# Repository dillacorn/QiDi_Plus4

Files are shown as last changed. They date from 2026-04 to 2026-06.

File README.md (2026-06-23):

# QiDi_Plus4

My Orca Slicer settings for the QiDi Plus4, with QiDi Box support and maintained Klipper `gcode_macro.cfg` / `printer.cfg` adjustments that can be changed in the Fluidd UI.

## Important warnings

### Filament temperature swaps

* Be careful when switching from high temperature filaments to lower temperature filaments.
* The cutter can leave high temp filament in the hotend.
* Feeding lower temp filament after that can cause a jam.
* For mixed temperature swaps, manual unload and manual load is the safest method.
* If you manually extract high temp filament that is linked to the QiDi Box, also unload it from the QiDi Box afterward.

### Manual spool / NO AMS printing

* For manual spool printing while the QiDi Box is connected, use the `NO AMS` Orca printer profile.
* The `NO AMS` profile uses `AMS=0`, skips QiDi Box startup logic, and does not call `T0`.
* Without the `NO AMS` profile, start the print from the printer screen and disable QiDi Box there.
* A separate manual spool profile is optional, but it helps prevent mistakes.

### QiDi Box / AMS notes

* If a spool is unraveling in the QiDi Box AMS, check your rollers.
* QiDi Box essentially ruined one of my spools because a roller was not rolling smoothly.
* I resolved it by swapping rollers around. They pull out easily.

### Stock touchscreen / QIDI screen stack

I no longer use the stock QiDi Plus4 touchscreen.

On my setup, the stock screen / Makerbase stack kept running background processes such as `xindi` / `QIDILink-client` even when I was mainly using Fluidd. While troubleshooting repeated `MCU: Timer Too Close` and main-MCU communication shutdowns, `xindi` was one of the heavier CPU users on the printer host.

I now leave the stock screen disconnected and use Fluidd from a separate laptop / touchscreen device instead. This keeps the printer host focused on Klipper, Moonraker, Fluidd, and webcam streaming instead of also running the stock screen UI.

This is optional. If you rely on the stock screen, do not disable it.

Use the optional tuning script to disable, verify, or re-enable the stock screen / Makerbase stack:

[plus4-optional-tuning.sh](https://github.com/dillacorn/QiDi_Plus4/blob/main/plus4-optional-tuning.sh)

In the script menu:

* `Apply optimizations` → `Disable QIDI screen service / xindi completely`
* `Undo optimizations` → `Re-enable QIDI screen service / xindi`
* `View status` → check whether the QIDI screen / QIDILink processes are running

### External KlipperScreen client

If you want a compact touchscreen-style control UI without running KlipperScreen on the Plus4 host board, run KlipperScreen from a separate laptop or touchscreen device instead.

Guide:

[External KlipperScreen Client](docs/external-klipperscreen-client/README.md)

This keeps the KlipperScreen UI load off the printer host while still allowing control through Moonraker.

## Z-offset note

<sub>Source / credit: [Kuo Steps for Improving Z-Offset Reliability](https://github.com/qidi-community/Plus4-Wiki/blob/main/content%2FKuo-Steps-for-Improving-Z-Offset-Reliability%2FREADME.md)</sub>

In `gcode_macro.cfg` in the Fluidd UI, the default `get_zoffset` value is:

```jinja
{% set p = (-0.15 + printer.gcode_move.homing_origin.z)|float %}
```

My current value is:

```jinja
{% set p = (-0.07 + printer.gcode_move.homing_origin.z)|float %}
```

Do not treat `-0.15` as the correct value for every machine.

Use it as a starting point only. You will likely need to adjust this yourself based on your machine, filament, bed surface, and print temperatures until first-layer squish is correct.

## Bed leveling and tramming

I no longer use the stock printer screen, so I do bed leveling from the Fluidd console using the QiDi macros.

Do **not** use the generic Fluidd bed-mesh button if it only sends:

```gcode
BED_MESH_CALIBRATE
```

Use the QiDi bed-level macros instead:

```gcode
QIDI_BED_LEVEL_60
```

for PLA / low-temp bed leveling, or:

```gcode
QIDI_BED_LEVEL_100
```

for ASA / ABS bed leveling.

These macros follow the QiDi leveling path and are safer than running a bare `BED_MESH_CALIBRATE` from Fluidd.

If your bed mesh shows around `0.30` or higher out of level, re-tram the bed and recalibrate using `Z_TILT_ADJUST` plus the QiDi bed reset / bed-level macro path.

For the closest tram possible, I recommend this bed tramming tool:

[QiDi Plus 4 Bed Tramming Tool](https://www.printables.com/model/1364372-qidi-plus-4-bed-tramming-tool)

Use paper to manually find an even level. The paper should have some resistance under the nozzle, but it should still move without binding hard.

I recommend running the QiDi bed reset procedure at least twice.

While doing this, apply light pressure to the center of the bed so it sits completely flat. I have noticed the bed can have a little bit of give, and using a consistent pressure point helps get a closer tram. Release pressure and re-check the paper at the center and all four corners during the procedure.

## Recommended Plus4 upgrades

I recommend printing these mods in ASA.

### CNC-Machined Aluminum Extruder Tension Bar

After roughly six months of heavy use, my stock plastic extruder tension bar developed significant warping and flex. I highly recommend replacing it with the CNC-machined aluminum version for better long-term rigidity and consistent extruder tension.

- [QIDI 3D Printer Aluminum Extruder Tension Bar Upgrade](https://www.etsy.com/listing/4514278258/qidi-3d-printer-aluminum-extruder)
- [Photos, installation, and comparison](docs/Alu_Tension_Bar/README.md)

### HEPA filter and activated charcoal setup

* [Flush-fit HEPA filter with refillable charcoal tray](https://www.printables.com/model/1148756-qidi-plus-4-hepa-filter-flush-fit-with-refillable)
* [Activated carbon](https://www.amazon.com/Carbon-Filtration-Activated-Depot-Replacement/dp/B0DJTSD8K8)
* [HEPA filter material](https://www.amazon.com/dp/B075L64BM7)

### Exhaust and VOC / fume setup

* [Exhaust setup](https://www.thingiverse.com/thing:6794215)
* [4-inch duct line](https://www.amazon.com/iPower-Flexible-Inch-Feet-Aluminum/dp/B09B1TK2WL)
* [Adjustable 120mm fan](https://www.amazon.com/Easy-Cloud-Plug-120mm-Controller-Brushless/dp/B0BG4C9H5P)
* [120mm to 4-inch duct adapter](https://www.printables.com/model/820287-adapter-for-120mm-fan-to-4-inch-duct)
  Print two.
* [4-inch window duct mount](https://www.amazon.com/HOXHA-Window-Ducting-Portable-Inline/dp/B0FF4JRX53?s=appliances)

### QiDi Box mods

* [Bowden tube support / bracket for QiDi Box](https://www.printables.com/model/1408927-bowden-tube-support-qidi-plus-4-bracket-for-qidi-b)
* [Jam-resistant filament guide](https://www.printables.com/model/1386069-qidi-box-jam-resistant-filament-guide/files)
* [Bowden Y-splitter for QiDi Box AMS PC4-M6](https://www.printables.com/model/1413138-bowden-y-splitter-for-qidi-box-ams-pc4-m6)
* [Extended angled spool holder for use with QiDi Box](https://www.printables.com/model/1477082-qidi-plus-4-extended-angled-spool-holder-use-with)
* [Second spool holder and QiDi Box bracket](https://www.printables.com/model/1396483-qidi-plus-4-spool-holder-and-qidi-box-bracket/files)
* [AMS Saver Filament Guide](https://www.printables.com/model/710471-ams-saver-filament-guide)
* [Qidi Box Filament Saver PC4-M6](https://www.printables.com/model/1572525-qidi-box-filament-saver-pc4-m6m10)
  Note: remove the metal ring from the inlet first. Push the Bowden tube fully through the M6 nut and up to the entry point. While installing the part, hold the fitting release collar and press carefully to avoid bending or damaging the Bowden tube.
* [(Almost) Universal Spool Weight](https://www.printables.com/model/1385589-almost-universal-spool-weight-for-qidibox-mmu-unit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)
  Note: If your spool is too light or the filament is not taut enough, you may experience feeding issues. I’ve found that adding weight to the spool can improve automatic loading success and may be necessary depending on the roll and remaining filament weight. Print 4 of these, use an M6 bolt to close off the entry hole, and fill them with 4.5 mm BBs. I recommend starting around 200–300 g total added weight, then increasing only if needed.
* [PTFE Guide Clip](https://www.printables.com/model/1462946-qidi-q2qidi-plus-4-ptfe-guide-clip/remixes)
  Note: Helps keep filament inline with extruder feeding.

### Cooling and exhaust mods

* [8038 exhaust fan shroud](https://www.printables.com/model/1560525-qidi-plus-4-8038-exhaust-fan-shroud)
* 80x80x38mm 24v 2-pin 3500-4200rpm fan
* [Hex mainboard cover for 80mm fan](https://www.printables.com/model/1146502-qidi-plus-4-hex-mainboard-cover-for-80mm-fan-with)
* [Fan grille](https://www.amazon.com/dp/B01CU72VS4)
* [80mm fan filter](https://www.amazon.com/Optimized-Computer-Airflow-Dustproof-80x80mm/dp/B07WCMKZ2S?nsdOptOutParam=true)
  Note: Keeps the dust out.

### 3D printed mods

* [PTFE hose anti-wear](https://www.printables.com/model/613216-ptfe-hose-anti-wear-for-bambu-lab-p1s-p2s-x1)
* [Rear chamber cover](https://www.printables.com/model/1040774-qidi-plus-4-rear-chamber-cover)
* [Hotend air duct](https://www.printables.com/model/1033699-qidi-plus-4-hotend-air-duct)
* [QiDi Plus4 plugs](https://www.printables.com/model/1161265-qidi-4-plus-plugs)
* [Cable ramp v3 screw mount](https://www.printables.com/model/1504994-qidi-plus-4-cable-ramp-v3-screw-mount)
* [Repositioned camera bracket](https://cults3d.com/en/3d-model/tool/qidi-plus-4-repositioned-camera-bracket)
* [Door seal with guide rails](https://www.printables.com/model/1504418-qidi-plus-4-door-seal-with-guide-rails)
* [Door seal](https://www.printables.com/model/1271100-qidi-plus-4-door-seal)
* [Simple poop box](https://www.printables.com/model/1214325-qidi-plus-4-poop-box/files)
* [Poop chute alternative](https://www.printables.com/model/1337616-qidi-plus-4-poop-chute/comments)
* [Chamber motherboard cover](https://www.printables.com/model/1040774-qidi-plus-4-rear-chamber-cover)
* [Toolhead covers light](https://cults3d.com/en/3d-model/tool/qidi-plus-4-toolhead-covers-light)
  Note: I recommend printing only the front cover and skipping the backplate. The backplate looks good, but it exposes the internal toolhead electronics more than I personally prefer, especially when printing fume-heavy materials like ASA and ABS long term. It works fine, but I do not see much practical benefit to using it.
* [Poop chute guide](https://www.printables.com/model/1019715-reloadeable-poop-bucket-for-qidi-x-plus-4/comments)
  Note: I like the open poop chute guide from this model. I use it to catch purged filament and help it fall straight down into the bucket.

## Performance tuning

The QiDi Community Plus4 Wiki has a system tuning guide that may help with repeatable `MCU: Timer Too Close` shutdowns.

The stability setup I currently use while avoiding `MCU: Timer Too Close` problems:

* Stock screen disconnected.
* `makerbase-client.service` disabled and masked.
* WiFi USB dongle removed.
* X/Y/Z/Z1 `run_current` reduced from my previous `1.15A` test value to `1.11A`.
* `cooling_fan` `tachometer_poll_interval` changed from `0.0015` to `0.010`.
* Printer-side Orca timelapse G-code removed.
* Fluidd is used from a separate laptop / touchscreen device.
* KlipperScreen, if used, is run externally from a separate laptop instead of on the Plus4 host.

These changes are not mandatory. They are meant to reduce host CPU load, USB/device activity, and extra mainboard stress on my setup.

* [QiDi Plus4 System Tuning Guide](https://github.com/qidi-community/Plus4-Wiki/blob/main/content/system-tuning/README.md)

The tuning script sets the printer host CPU to performance mode and adjusts CPU affinity so Klipper has less interference from other services.

I recommend doing this only after upgrading the mainboard cooling fan / board cooling setup, since performance mode keeps the host CPU running at a higher speed.

This is optional, but may help if you use webcam streaming, timelapse, Obico, or other monitoring services.

## Obico / timelapse note

I removed the printer-side timelapse G-code from my Orca Slicer printer profiles.

If you use Obico, webcam streaming, Fluidd, or any other monitoring service, I strongly recommend leaving Orca's printer-side timelapse G-code empty unless you specifically need layer-change snapshots.

In Orca Slicer:

`Printer profile > Machine G-code > Time lapse G-code`

Leave the **Time lapse G-code** box empty.

This prevents Orca from inserting `TIMELAPSE_TAKE_FRAME` into every sliced G-code file. On the QiDi Plus4, this reduces unnecessary camera/screenshot/file-writing activity during prints, lowers extra host CPU load, and may help reduce the chance of rare `MCU: Timer Too Close` shutdowns. It also avoids extra write activity on the printer's internal eMMC storage.

If you insist on using layer-change timelapse G-code, use the lighter version below instead:

```gcode
{if timelapse_type == 1} ; timelapse with wipe tower
TIMELAPSE_TAKE_FRAME
{elsif timelapse_type == 0} ; timelapse without wipe tower
TIMELAPSE_TAKE_FRAME
{endif}
```

## Supplemental guides

* [External KlipperScreen Client](docs/external-klipperscreen-client/README.md)
  Run KlipperScreen from a separate laptop / touchscreen device instead of on the Plus4 host board.

* [Corsi-Rosenthal Box](docs/CR_Box/README.md)
  Supplemental room air filtration for the printer area. This is not a replacement for printer exhaust, HEPA filtration, activated charcoal, or proper ventilation.

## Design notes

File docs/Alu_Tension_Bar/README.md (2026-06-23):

# CNC-Machined Aluminum Extruder Tension Bar

After roughly six months of heavy use, the stock plastic extruder tension bar in my QiDi Plus4 developed significant warping and flex.

The CNC-machined aluminum replacement is substantially more rigid and eliminates the visible deformation present in the original plastic part. I highly recommend this upgrade for long-term reliability and more consistent extruder tension.

## Purchase Link

[QIDI 3D Printer Aluminum Extruder Tension Bar Upgrade](https://www.etsy.com/listing/4514278258/qidi-3d-printer-aluminum-extruder)

I purchased this part myself and posted a verified Etsy review on the product listing.

## Stock Plastic Tension Bar

The original plastic tension bar developed visible warping after extended heavy use.

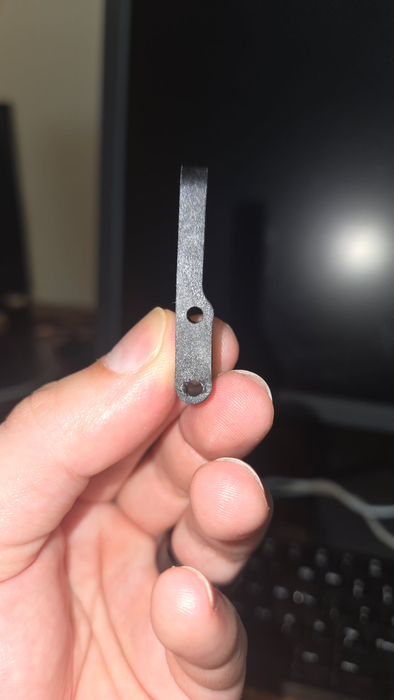
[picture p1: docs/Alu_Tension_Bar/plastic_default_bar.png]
Warped stock plastic tension bar


## Aluminum Tension Bar

The CNC-machined aluminum replacement remains rigid and shows no visible bending or warping. (sorry blurry image)

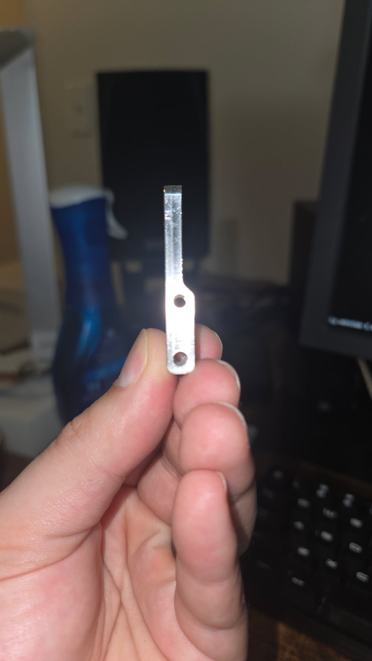
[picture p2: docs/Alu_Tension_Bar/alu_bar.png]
CNC-machined aluminum tension bar


## Gear Installation

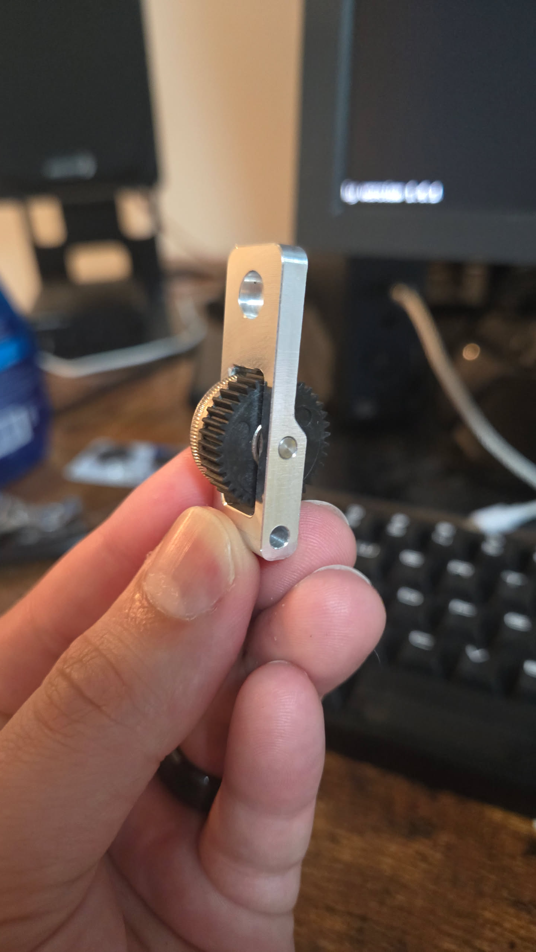
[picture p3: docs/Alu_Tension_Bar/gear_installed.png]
Extruder gear installed in the aluminum tension bar


## Installed in the Extruder

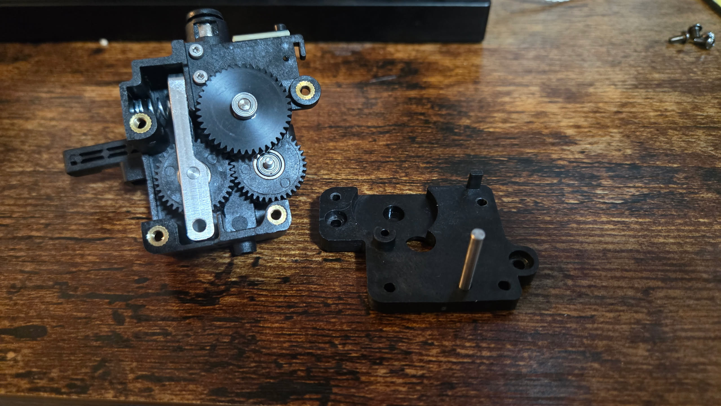
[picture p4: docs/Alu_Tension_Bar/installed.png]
Aluminum tension bar installed in the QiDi Plus4 extruder


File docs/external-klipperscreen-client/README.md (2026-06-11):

# External KlipperScreen Client

This guide shows how to run KlipperScreen from a separate laptop or desktop instead of running it on the QiDi Plus4 host board.

The goal is to keep the Plus4 focused on Klipper, Moonraker, Fluidd, and webcam streaming while moving the KlipperScreen UI load to another device.

## Why run KlipperScreen externally?

The QiDi Plus4 host board has limited overhead. Running extra UI software directly on the printer can increase host CPU load and may contribute to Klipper communication instability or MCU timeout issues.

Running KlipperScreen on another device avoids that problem:

```text
Printer host:
- Klipper
- Moonraker
- Fluidd
- webcamd / mjpg-streamer

External laptop:
- KlipperScreen UI
```

This does not replace Fluidd. It provides a compact touchscreen-style control interface that connects to Moonraker remotely.

## Tested setup

```text
Printer: QiDi Plus4
Printer Moonraker address: qidi.time-puffin.ts.net:7125
Client device: Arch Linux laptop
KlipperScreen installed on: external laptop only
```

Do not install or enable this KlipperScreen setup on the Plus4 host board.

## Install KlipperScreen on Arch Linux

```bash
sudo pacman -S klipperscreen
```

The Arch package installs KlipperScreen under:

```text
/opt/klipperscreen/
```

Run it manually with:

```bash
cd /opt/klipperscreen
python screen.py
```

## KlipperScreen config path

KlipperScreen should read its user config from:

```text
~/.config/KlipperScreen/KlipperScreen.conf
```

Create the config directory:

```bash
mkdir -p ~/.config/KlipperScreen
```

Copy the repo config into place from the repository root:

```bash
cp docs/external-klipperscreen-client/config/KlipperScreen/KlipperScreen.conf ~/.config/KlipperScreen/KlipperScreen.conf
```

Or, if you are already inside `docs/external-klipperscreen-client/`:

```bash
cp config/KlipperScreen/KlipperScreen.conf ~/.config/KlipperScreen/KlipperScreen.conf
```

Edit the installed config:

```bash
nano ~/.config/KlipperScreen/KlipperScreen.conf
```

Replace the placeholder Moonraker API key with your real Moonraker API key.

Do not commit your real API key to a public repo.

## Connection options

The included repo config is stored at:

```text
docs/external-klipperscreen-client/config/KlipperScreen/KlipperScreen.conf
```

The installed config should live at:

```text
~/.config/KlipperScreen/KlipperScreen.conf
```

For local LAN access, set the printer host in `~/.config/KlipperScreen/KlipperScreen.conf` to:

```text
192.168.68.118
```

For Tailscale/MagicDNS access, set the printer host to:

```text
qidi.time-puffin.ts.net
```

For HTTPS through Tailscale Serve, set the port to `443` and enable SSL in `~/.config/KlipperScreen/KlipperScreen.conf`.

Only use the HTTPS version if this test works:

```bash
curl -fsS https://qidi.time-puffin.ts.net/server/info | python -m json.tool
```

For direct Moonraker access on port 7125, use:

```bash
curl -fsS http://qidi.time-puffin.ts.net:7125/server/info | python -m json.tool
```

## Test Moonraker access

Run this from the external laptop:

```bash
curl -fsS http://qidi.time-puffin.ts.net:7125/server/info | python -m json.tool
curl -fsS http://qidi.time-puffin.ts.net:7125/printer/info | python -m json.tool
```

If using the LAN IP:

```bash
curl -fsS http://192.168.68.118:7125/server/info | python -m json.tool
curl -fsS http://192.168.68.118:7125/printer/info | python -m json.tool
```

If these commands fail, fix networking or Moonraker authorization before troubleshooting KlipperScreen.

## Launch KlipperScreen

```bash
cd /opt/klipperscreen
python screen.py
```

If it fails, run it with logs visible:

```bash
cd /opt/klipperscreen
python screen.py 2>&1 | tee ~/klipperscreen-run.log
```

## Notes

* This is meant to run on an external client device, not the Plus4 host board.
* Keep the real Moonraker API key out of public commits.
* `show_cursor: True` makes KlipperScreen usable with a mouse or trackpad.
* `keyboard_navigation: True` improves laptop usability.
* The custom menu entries make Move and Home controls easier to access from the main screen.
* Homing commands will move the printer. Only press Home buttons when the printer is physically clear and ready.

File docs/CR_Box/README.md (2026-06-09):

# Corsi-Rosenthal Box

This folder contains the parts list, cut notes, and reference images for a 140mm fan Corsi-Rosenthal Box build.

This is supplemental room air filtration for the printer area. It is not a replacement for printer exhaust, HEPA filtration, activated charcoal, or proper ventilation.

## Printed parts

* [Thingiverse model](https://www.thingiverse.com/thing:7014064)

## Parts

### Plywood / underlayment panel

Used for the thin side panels.

The model calls for:

* `1/4 in nominal plywood`
* `5.5 mm actual thickness`
* `4 ft x 4 ft panel`

Cheaper usable option:

* [Home Depot - Tri-PLY 5.0mm x 4 ft x 4 ft Underlayment](https://www.homedepot.com/p/Tri-PLY-Underlayment-Common-5-0-mm-x-4-ft-x-4-ft-Actual-0-196-in-x-47-75-in-x-48-in-448887/202327787)

This panel is listed as:

* `5.0 mm common thickness`
* `0.196 in actual thickness`
* `47.75 in x 48 in actual size`

This is slightly thinner than the original model spec, but should fit a `6 mm` printed slot without issue. If it fits loose, use thin foam tape, hot glue, or a small printed shim.

Avoid plywood much thicker than `5.5 mm`, since true `1/4 in` plywood can be close to `6 mm` and may be tight in the printed slot.

Panel cut list:

* `8.5" x 24 3/8"` x2 long panels
* `8.5" x 15 3/8"` x2 short panels

Decimal cut sizes:

* `8.5" x 24.375"` x2 long panels
* `8.5" x 15.375"` x2 short panels

A single `4 ft x 4 ft` panel is enough for the listed cut sizes.

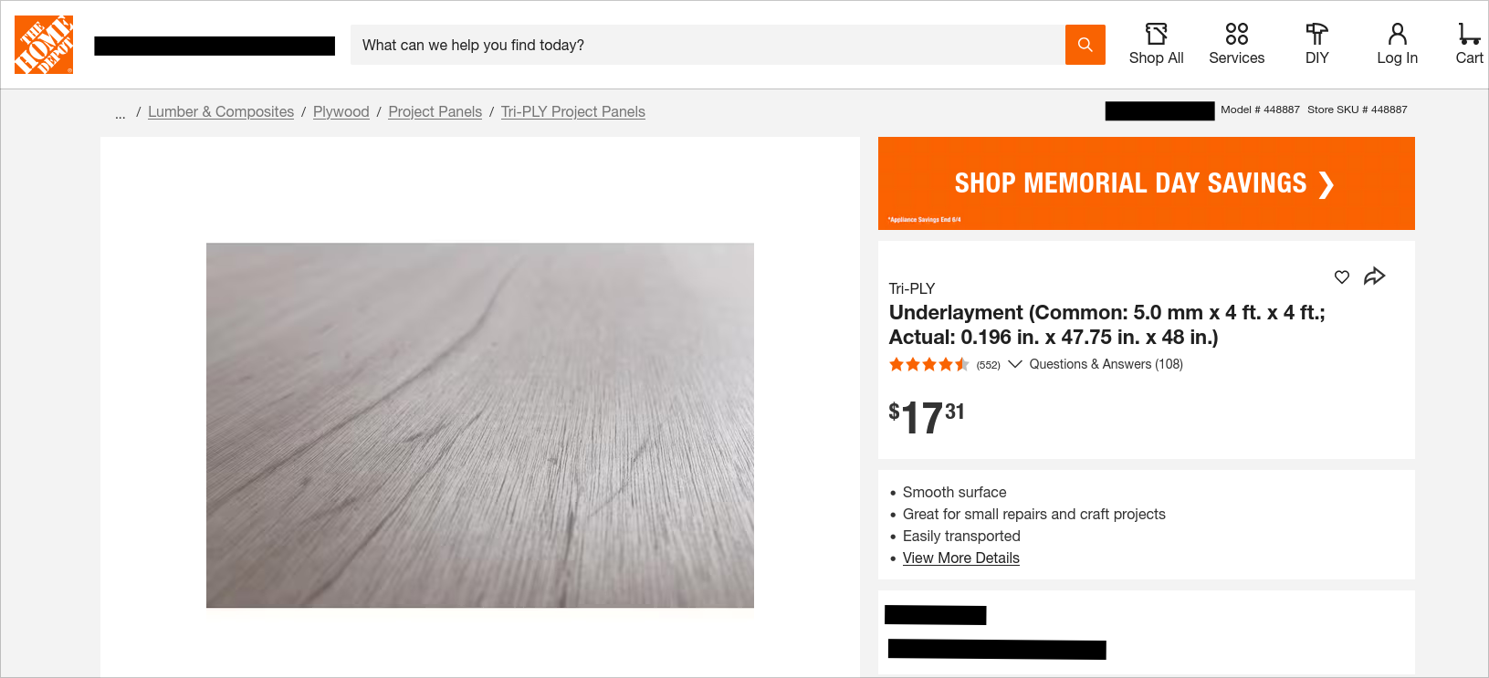
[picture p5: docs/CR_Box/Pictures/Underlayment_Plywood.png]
Underlayment plywood panel


### Wood dowels

Used for the box frame.

The model uses `5/8 in x 5/8 in` square wooden dowels.

* [Home Depot - Waddell 5/8 in x 36 in square wood dowel](https://www.homedepot.com/p/Waddell-Pine-Square-Dowel-36-in-x-0-625-in-Sanded-and-Ready-for-Finishing-Versatile-Wooden-Rod-for-DIY-Home-Projects-8210U/329566340)

Buy quantity:

* `36"` dowels x4

Dowel cut list:

* `22 3/8"` x4 long dowels
* `13 3/8"` x4 short dowels

Decimal cut sizes:

* `22.375"` x4 long dowels
* `13.375"` x4 short dowels

If using `36"` dowels, each dowel should provide one long piece and one short piece when accounting for a standard saw kerf.

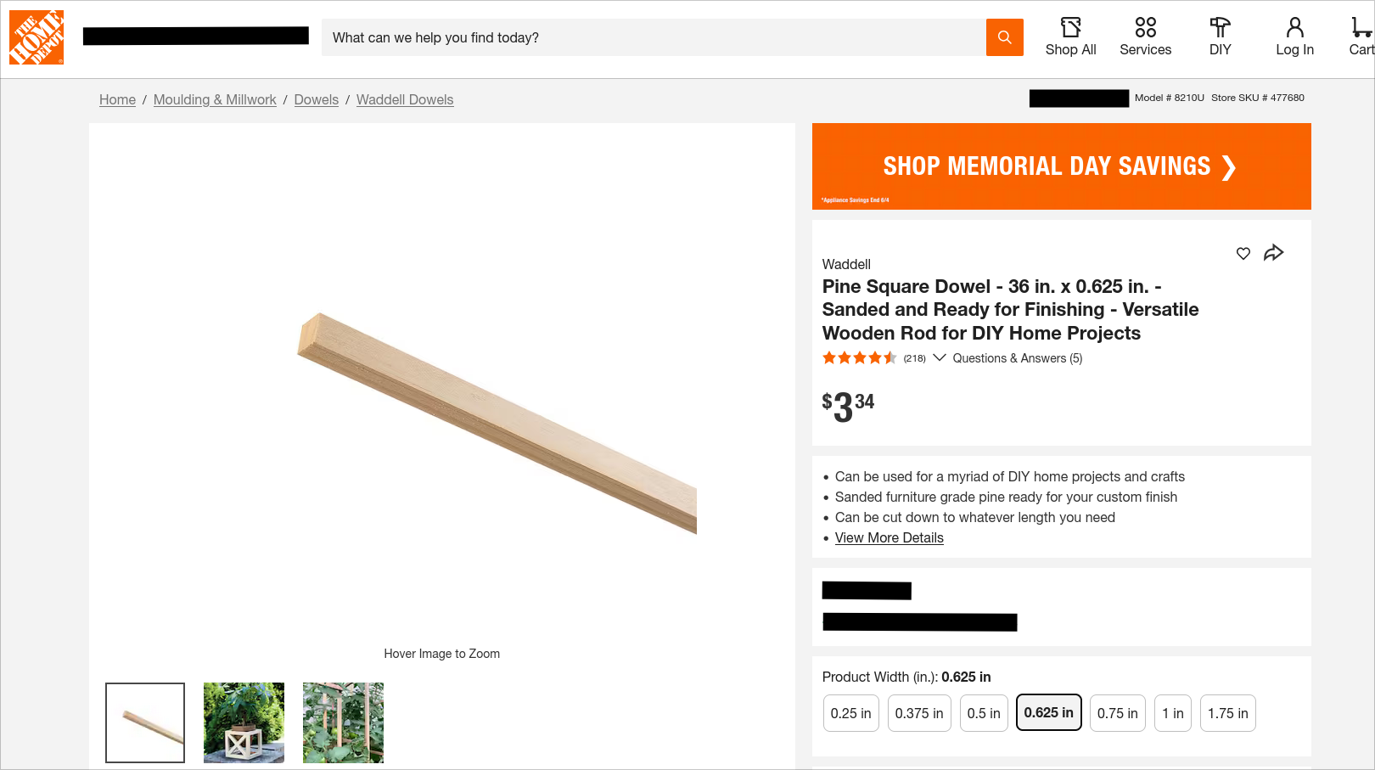
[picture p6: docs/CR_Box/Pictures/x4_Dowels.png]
5/8 square wood dowels


### Adjustable power adapter / fan power control

Used to power and control the fans.

* [Amazon - adjustable power adapter](https://www.amazon.com/dp/B0FBKBD3C/?psc=1)

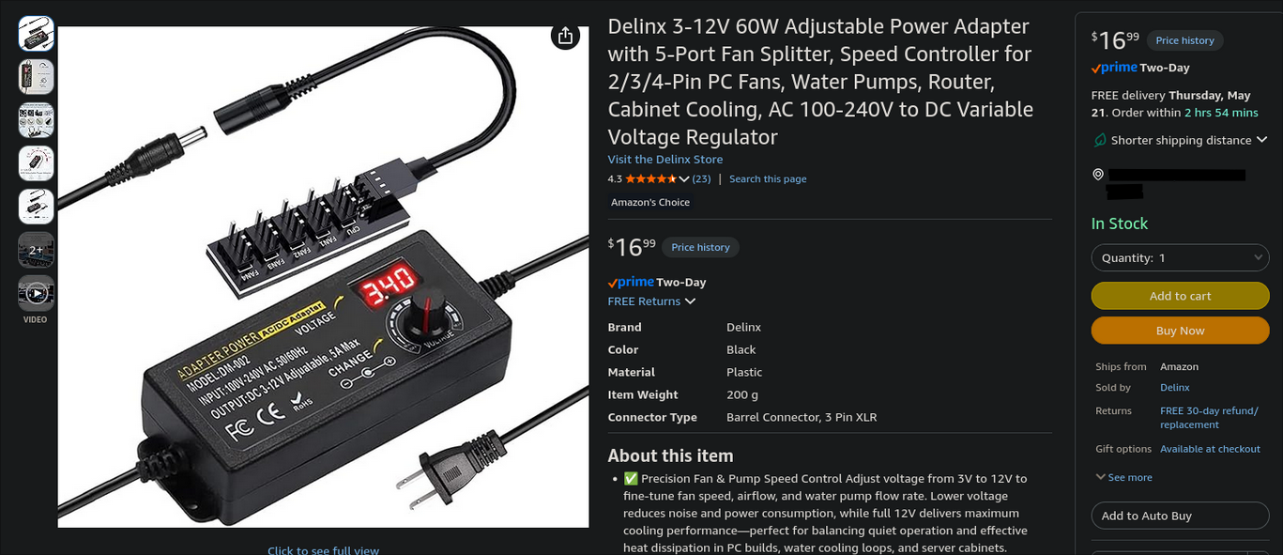
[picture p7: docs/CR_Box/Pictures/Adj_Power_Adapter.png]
Adjustable power adapter


### 140mm fans

This build uses 140mm PC fans. A 5-pack gives one extra fan if the model only uses four.

* [Amazon - ARCTIC P14 Pro PST 5-pack](https://www.amazon.com/dp/B0DPX94PSL/?psc=1)

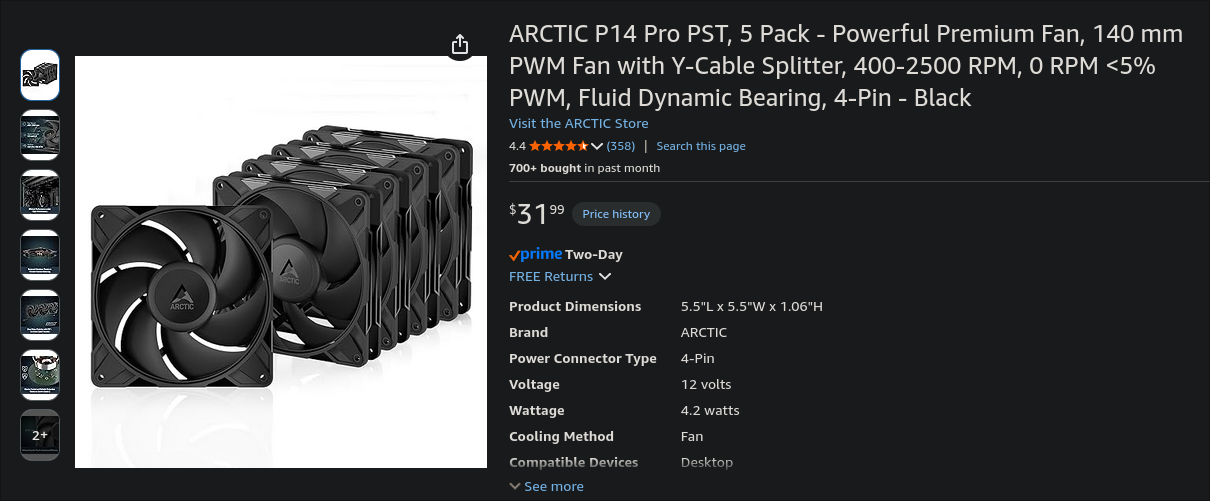
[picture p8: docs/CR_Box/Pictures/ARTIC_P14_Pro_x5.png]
ARCTIC P14 Pro 5-pack


### 16 x 25 x 1 MERV 13 filters

Used as the main filter panels.

* [Amazon - BNX 16x25x1 MERV 13 filter 4-pack](https://www.amazon.com/dp/B09XFKZB2C/?psc=1)

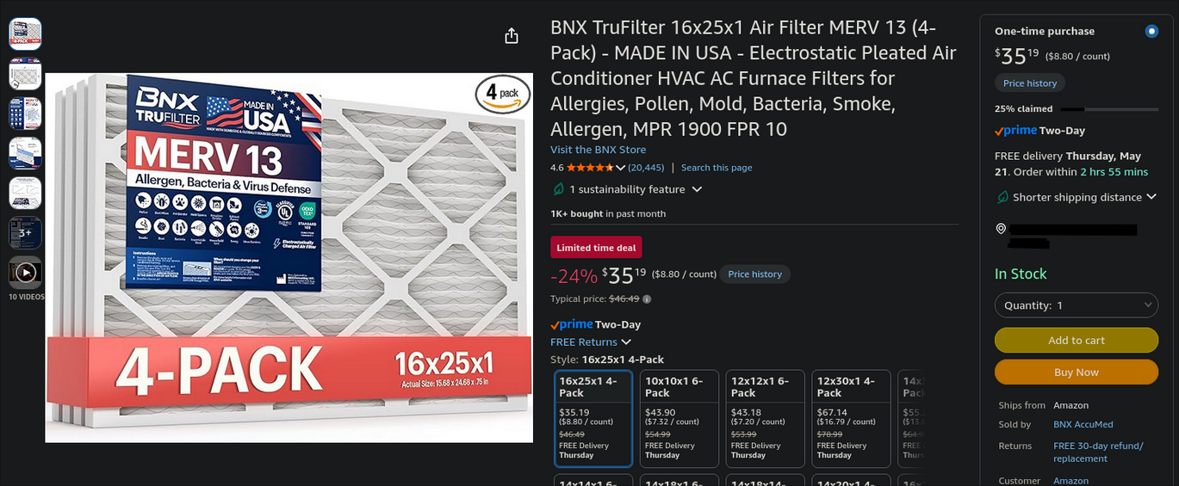
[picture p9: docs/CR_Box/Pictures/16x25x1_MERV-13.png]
16x25x1 MERV 13 filter


## Cutting notes

Use a cutting optimizer such as OptiCutter to position the panel and dowel cuts.

Remember to include the width of your saw blade, also called the kerf.

Measure twice, cut once.

## Use notes

* Use MERV 13 or better filters.
* Make sure the airflow arrows on the filters point inward toward the fan.
* Add a cardboard or printed shroud on the fan outlet side if the design supports it.
* Do not point the fan directly at the printer enclosure if it causes drafts or chamber temperature instability.
* Run it during and after ASA / ABS prints as extra room air cleanup.
* For fumes, odor, and VOC reduction, keep using activated charcoal and/or exhaust ventilation.

## Notes

This is supplemental room filtration.

It is not a replacement for:

* printer exhaust
* HEPA filtration
* activated charcoal
* window ducting
* proper ventilation

For ASA / ABS printing, still vent and filter the printer enclosure properly.

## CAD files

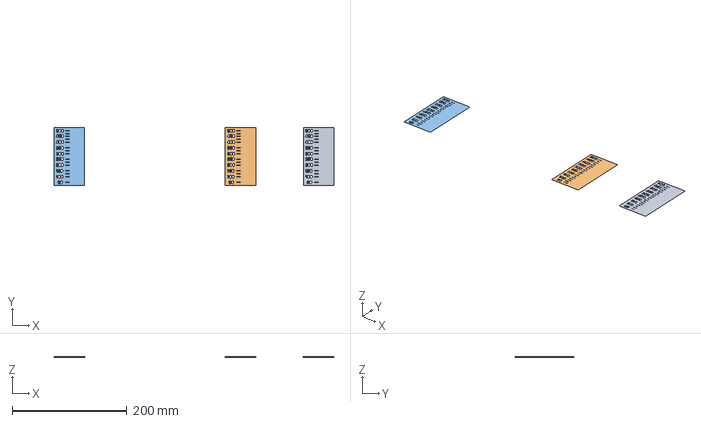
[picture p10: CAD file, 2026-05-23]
3mf_Tests/AMS+Purge+Calibration_Plus4.3mf
487.4 x 101.7 x 0.2 mm
(Non salvato).stl x 3

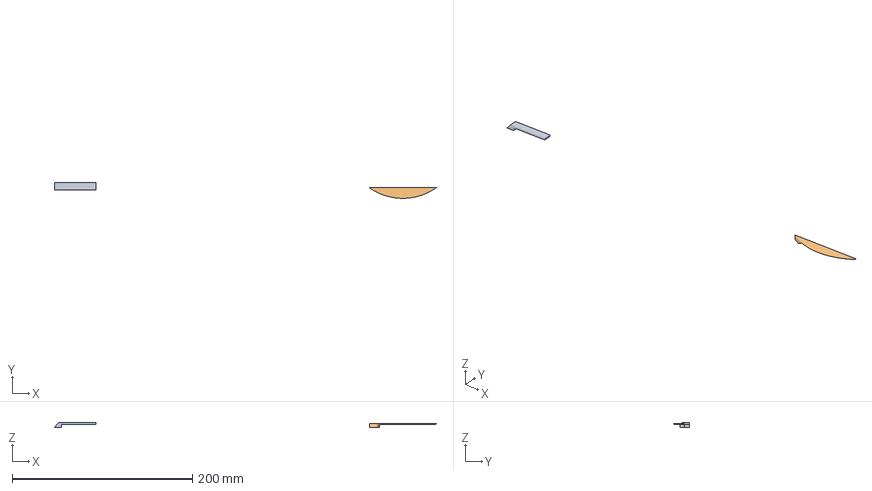
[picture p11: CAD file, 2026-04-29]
3mf_Tests/support_top_z_dist-curve&straight_test.3mf
424.0 x 17.4 x 5.00 mm
half_bridge_test.stl
half_curve_bridge_test.stl

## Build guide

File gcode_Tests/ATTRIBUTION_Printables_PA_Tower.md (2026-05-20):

# Attribution

This folder references a pressure advance calibration tower model from Printables.

## Source model

- **Title:** Calibration Tower - Pressure Advance (M572) or Linear Advance (M900)
- **Author:** SJB4127 / @SJB4127
- **Source:** https://www.printables.com/model/909107-calibration-tower-pressure-advance-m572-or-linear
- **Platform:** Printables
- **License:** Creative Commons Attribution-NonCommercial-NoDerivatives 4.0 International (CC BY-NC-ND 4.0)
- **License URL:** https://creativecommons.org/licenses/by-nc-nd/4.0/
- **Model origin:** Marked by the author as their own original creation on Printables

## Repository note

This repository does not redistribute the original STL/3MF model files from the Printables listing.

Because the listed license includes **NoDerivatives**, modified or printer-specific sliced G-code generated from this model should not be redistributed here. Keep only notes, settings, screenshots, or instructions that describe how the pressure advance test was run.

## Local calibration settings used

The following values were used only for personal calibration on a QiDi Plus4 and are not part of the original model license:

- Firmware command: `M900 K<value>`
- ABS / ASA test range: `0.015`, `0.035`, `0.055`, `0.075`
- TPU 95A test range: `0.040`, `0.070`, `0.100`, `0.130`
- Cancel behavior used for test prints: stop/cancel at layer 195

## Attribution text

Pressure advance calibration tower model by SJB4127 / @SJB4127 on Printables, licensed under CC BY-NC-ND 4.0.
Source: https://www.printables.com/model/909107-calibration-tower-pressure-advance-m572-or-linear
License: https://creativecommons.org/licenses/by-nc-nd/4.0/

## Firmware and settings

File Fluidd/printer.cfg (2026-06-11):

# QIDI Plus4 V1.0.0

[include plr.cfg]
[include gcode_macro.cfg]
[include time_update.cfg]

# Plugins
[include timelapse.cfg]
[include KAMP_Settings.cfg]
[include box.cfg]

[mcu]
serial: /dev/ttyS2
restart_method: command
baud:500000

[mcu U_1]
serial: /dev/ttyS0
restart_method: command
baud:500000

[temperature_sensor GD32]
sensor_type: temperature_mcu
sensor_mcu: mcu

[respond]
default_type: echo

[save_variables] 
filename =/home/mks/printer_data/config/saved_variables.cfg

[resonance_tester]
accel_per_hz: 150
max_smoothing:0.5

[duplicate_pin_override]
pins:

[bed_screws]
screw1:25,21
screw1_name: Front left
screw2: 285,21
screw2_name: Front right
screw3: 285,281
screw3_name: Last right
screw4: 25,281

[screws_tilt_adjust]
screw1:0,20
screw1_name: Front left
screw2: 260,20
screw2_name: Front right
screw3: 260,280
screw3_name: Back right
screw4: 0,280
screw4_name: Back left
screw_thread: CW-M4

[hall_filament_width_sensor]
adc1: PA2
adc2: PA3
cal_dia1: 1.50
cal_dia2: 2.0
raw_dia1: 14197
raw_dia2: 15058
default_nominal_filament_diameter: 1.75
max_difference: 0
measurement_delay: 50
enable: false
measurement_interval: 10
logging: False
min_diameter: 0.3
use_current_dia_while_delay: False
pause_on_runout: False
event_delay: 3.0
pause_delay: 0.5

[extruder]
step_pin:PB9
dir_pin:PB8
enable_pin:!PC15
rotation_distance: 53.7  #22.6789511 Bondtech 5mm Drive Gears
gear_ratio: 1517:170
microsteps: 16
full_steps_per_rotation: 200 #200 for 1.8 degree, 400 for 0.9 degree
nozzle_diameter: 0.400
filament_diameter: 1.75
min_temp: 0
max_temp: 380
min_extrude_temp: 175
smooth_time: 0.000001
heater_pin:PB3
sensor_type:MAX6675
sensor_pin:PB12
spi_speed: 100000
spi_software_sclk_pin:PB13
spi_software_mosi_pin:PA11
spi_software_miso_pin:PB14
max_power: 1

control : pid  
pid_Kp=33.555
pid_Ki=4.76
pid_Kd=59.141

pressure_advance: 0.032
pressure_advance_smooth_time: 0.03
max_extrude_cross_section:500
instantaneous_corner_velocity: 10.000
max_extrude_only_distance: 1000.0
max_extrude_only_velocity:5000
max_extrude_only_accel:5000
step_pulse_duration:0.000002

[tmc2209 extruder]
uart_pin:PC13
interpolate: True
run_current: 0.714
stealthchop_threshold: 0

[adxl345]
cs_pin:PA4
spi_software_sclk_pin:PA5
spi_software_mosi_pin:PA7
spi_software_miso_pin:PA6
axes_map: -x, z, -y

[printer]
kinematics: corexy
max_velocity: 600
max_accel: 20000
max_accel_to_decel: 10000
max_z_velocity: 20
max_z_accel: 500
square_corner_velocity: 5

[stepper_x]
step_pin:U_1:PB4
dir_pin:!U_1:PB3
enable_pin:!U_1:PB5
microsteps:32
rotation_distance: 38.82
full_steps_per_rotation:200 # set to 400 for 0.9 degree stepper
endstop_pin:tmc2240_stepper_x:virtual_endstop
position_min: -1.5
position_endstop: -1.5
position_max:307
homing_speed:50
homing_retract_dist:0
homing_positive_dir:False
step_pulse_duration:0.0000001

[stepper_y]
step_pin:U_1:PC14
dir_pin:!U_1:PC13
enable_pin:!U_1:PC15
microsteps: 32
rotation_distance: 38.82
full_steps_per_rotation:200 # set to 400 for 0.9 degree stepper
endstop_pin:tmc2240_stepper_y:virtual_endstop
position_min: -2
position_endstop: -2
position_max:325
homing_speed:50
homing_retract_dist:0
homing_positive_dir:False
step_pulse_duration:0.0000001

[stepper_z]
step_pin:U_1:PB1
dir_pin:U_1:PB6
enable_pin:!U_1:PB0
microsteps: 16
rotation_distance: 4
full_steps_per_rotation: 200
endstop_pin:probe:z_virtual_endstop # U_1:PC3 for Z-max
endstop_pin_reverse:tmc2209_stepper_z:virtual_endstop
position_endstop:1
position_endstop_reverse:285
position_max:285
position_min: -1
homing_speed: 10
homing_speed_reverse: 10
second_homing_speed: 5
homing_retract_dist: 5.0
homing_positive_dir:false
homing_positive_dir_reverse:true
#step_pulse_duration:0.0000001

[stepper_z1]
step_pin:U_1:PC10
dir_pin:U_1:PA15
enable_pin:!U_1:PC11
microsteps: 16
rotation_distance: 4
full_steps_per_rotation: 200
endstop_pin_reverse:tmc2209_stepper_z1:virtual_endstop
#step_pulse_duration:0.0000001

[z_tilt]
z_positions:
    -17.5,138.5
    335.7,138.5

points:
    0,138.5
    255,138.5

speed: 150
horizontal_move_z: 5
retries: 2
retry_tolerance: 0.05

[tmc2240 stepper_y]
cs_pin:U_1:PB9
spi_software_sclk_pin:U_1:PA5
spi_software_mosi_pin:U_1:PA7
spi_software_miso_pin:U_1:PA6
spi_speed:200000
run_current: 1.07
#hold_current: 0.5
interpolate:true
stealthchop_threshold:0
diag0_pin:!U_1:PC0
driver_SGT:1

[tmc2240 stepper_x]
cs_pin:U_1:PD2
spi_software_sclk_pin:U_1:PA5
spi_software_mosi_pin:U_1:PA7
spi_software_miso_pin:U_1:PA6
spi_speed:200000
run_current: 1.07
# hold_current: 0.5
interpolate:true
stealthchop_threshold:0
diag0_pin:!U_1:PB8
driver_SGT:1

[tmc2209 stepper_z]
uart_pin:U_1: PB7
run_current: 1.07
# hold_current: 0.17
interpolate: False
stealthchop_threshold: 9999999999
diag_pin:^U_1:PA13
driver_SGTHRS:100

[tmc2209 stepper_z1]
uart_pin:U_1: PC5
run_current: 1.07
# hold_current: 0.17
interpolate: False
stealthchop_threshold: 9999999999
diag_pin:^U_1:PC12
driver_SGTHRS:100

[heater_bed]
heater_pin: U_1:PB10
sensor_type:NTC 100K MGB18-104F39050L32
sensor_pin:U_1: PA0
max_power: 1.0
control = pid
pid_Kp=63.418 
pid_Ki=1.342 
pid_Kd=749.125
pwm_cycle_time:0.001
min_temp: -60
max_temp: 125

[heater_generic chamber]
heater_pin:U_1:PC8
max_power:0.4
sensor_type:NTC 100K MGB18-104F39050L32
sensor_pin:U_1:PA1

control = pid
pid_Kp=63.418 
pid_Ki=1.342 
pid_Kd=749.125

min_temp:-100
max_temp:70
target_min_temp:10
target_max_temp:65
heat_with_heater_bed:True
heat_with_heater_bed_tem_add:25

[verify_heater chamber]
max_error: 400
check_gain_time:600
hysteresis: 5
heating_gain: 2
position_z: 270

[temperature_sensor Chamber_Thermal_Protection_Sensor]
sensor_type:NTC 100K MGB18-104F39050L32
sensor_pin:U_1:PC2
min_temp:-100
max_temp:140

[verify_heater extruder]
max_error: 120
check_gain_time:20
hysteresis: 5
heating_gain: 1

[verify_heater heater_bed]
max_error: 200
check_gain_time:60
hysteresis: 10
heating_gain: 1

[fan_generic auxiliary_cooling_fan]
pin: U_1:PA8
shutdown_speed: 0.0
cycle_time: 0.0100
hardware_pwm: false
kick_start_time: 0.100
off_below: 0.0

[fan_generic chamber_circulation_fan]
pin: U_1:PC9
shutdown_speed: 0.0
cycle_time: 0.0100
hardware_pwm: false
kick_start_time: 0.100
off_below: 0.0

# [chamber_fan chamber_fan]
# pin:U_1:PA4
# max_power: 1.0
# shutdown_speed: 0
# kick_start_time: 0.5
# heater:chamber
# fan_speed: 1.0
# off_below: 0
# idle_timeout:60
# idle_speed:1.0

[temperature_fan adaptive_chamber_fan]
pin: U_1:PA4
max_power: 1.0
shutdown_speed: 1.0
kick_start_time: 0.5
off_below: 0.10
sensor_type: temperature_combined
sensor_list: temperature_sensor Chamber_Thermal_Protection_Sensor, temperature_sensor Chamber_Thermal_Protection_Sensor
combination_method: max
maximum_deviation: 999.9
control: pid
pid_deriv_time: 10.0
pid_Kp: 12.0
pid_Ki: 12.0
pid_Kd: 5.0
min_speed: 0.0
max_speed: 1.0
min_temp: 0
max_temp: 140
target_temp: 69.0

[heater_fan hotend_fan]
pin:PB5
max_power: 1.0
shutdown_speed:1.0
kick_start_time: 0.5
heater: extruder
heater_temp: 50.0
fan_speed: 1.0
off_below: 0

[heater_fan hotend_fan2]
pin:PB4
max_power: 1.0
shutdown_speed:1.0
kick_start_time: 0.5
heater: extruder
heater_temp: 50.0
fan_speed: 1.0
off_below: 0

[heater_fan hotend_fan3]
pin:PB10
max_power: 1.0
shutdown_speed:1.0
kick_start_time: 0.5
heater: extruder
heater_temp: 50.0
fan_speed: 1.0
off_below: 0

[fan_generic cooling_fan]
pin:PA8
max_power: 1.0
shutdown_speed:0
cycle_time: 0.010
hardware_pwm: False
kick_start_time: 0.100
off_below: 0.0
tachometer_pin:PA9
tachometer_ppr: 2
tachometer_poll_interval: 0.010

# [controller_fan board_fan]
# pin:U_1:PC4
# max_power:1.0
# shutdown_speed:1.0
# cycle_time:0.01
# fan_speed: 1.0
# heater:chamber
# stepper:stepper_x,stepper_y

[temperature_fan board_fan]
pin: U_1:PC4
max_power: 1.0
shutdown_speed: 1.0
cycle_time: 0.01
off_below: 0.10
sensor_type: temperature_mcu
sensor_mcu: U_1
control: pid
pid_deriv_time: 2.0
pid_Kp: 5.0
pid_Ki: 2.0
pid_Kd: 5.0
target_temp: 50.0
min_speed: 0.30
max_speed: 1.0
min_temp: 0
max_temp: 100

[output_pin caselight]
pin: U_1:PC7
pwm: false
shutdown_value:1
value:1

[output_pin beeper]
pin:U_1: PA2
pwm: false
shutdown_value:0
value:0

[output_pin ctlyd]
pin:U_1: PA14
pwm: false
shutdown_value:0
value:0

[smart_effector]
pin:U_1:PC1
recovery_time:0
x_offset: 25
y_offset: 1.3
z_offset: 0.000001
speed: 5
lift_speed: 18
probe_accel: 50
samples: 2
samples_result: submaxmin
sample_retract_dist: 8
samples_tolerance: 0.025
samples_tolerance_retries: 5

[qdprobe]
pin:!PA10
z_offset:0.000001

[bed_mesh]
speed:600
horizontal_move_z:5
mesh_min:25,10
mesh_max:295,295
probe_count:9,9
algorithm:bicubic
bicubic_tension:0.4
mesh_pps: 2,2

[filament_switch_sensor fila]
pause_on_runout: True
runout_gcode:
    M118 Filament tangle detected
event_delay: 3.0
pause_delay: 0.5
switch_pin:U_1:PC3

[resonance_tester]
accel_chip:adxl345
probe_points:
   150, 150, 10

[idle_timeout]
timeout: 43200
gcode:
    PRINT_END

[pause_resume]

[display_status]

[gcode_macro_break]

[virtual_sdcard]
path: ~/printer_data/gcodes
on_error_gcode: _QIDI_FAIL_CLOSED
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

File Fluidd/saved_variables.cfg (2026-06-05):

[Variables]
ams_loaded_tool = -1
auto_init_detect = 0
auto_reload_detect = 0
bed_temp = 100.0
box_count = 1
color_slot0 = 2
color_slot1 = 22
color_slot16 = 1
color_slot2 = 6
color_slot3 = 9
enable_box = 1
extrude_state = 0
filament_slot0 = 11
filament_slot1 = 18
filament_slot16 = 1
filament_slot2 = 18
filament_slot3 = 18
file_path = '/home/mks/gcode_files/.cache/3DBenchy.gcode'
filepath = ''
gcode_lines = 316450
hot_temp = 55.0
is_tool_change = 0
last_file = ''
last_load_slot = 'slot0'
load_retry_num = 0
power_resume_z = 58.0
print_temp = 260.0
profile_name = 'default'
retry_step = None
runout_0 = 0
runout_1 = 0
runout_10 = 0
runout_11 = 0
runout_12 = 0
runout_13 = 0
runout_14 = 0
runout_15 = 0
runout_2 = 0
runout_3 = 0
runout_4 = 0
runout_5 = 0
runout_6 = 0
runout_7 = 0
runout_8 = 0
runout_9 = 0
slot0 = 2
slot1 = 1
slot2 = 1
slot3 = 1
slot_sync = 'slot0'
value_t0 = 'slot0'
value_t1 = 'slot1'
value_t2 = 'slot2'
value_t3 = 'slot3'
vendor_slot0 = 0
vendor_slot1 = 0
vendor_slot16 = 0
vendor_slot2 = 0
vendor_slot3 = 0
was_interrupted = False
z_offset = 0

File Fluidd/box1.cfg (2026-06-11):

[box_stepper slot0]
runout_pin: mcu_box1:PA0
step_pin: mcu_box1:PC14
dir_pin: mcu_box1:PC13
enable_pin: !mcu_box1:PC15
microsteps: 16
rotation_distance: 13.6
white_pin: mcu_box1:PA1
red_pin: mcu_box1:PA2
step_pulse_duration:0.000000100

[box_stepper slot1]
runout_pin: mcu_box1:PB3
step_pin: mcu_box1:PB9
dir_pin: mcu_box1:PB8
enable_pin: !mcu_box1:PC0
microsteps: 16
rotation_distance: 13.6
white_pin: mcu_box1:PB4
red_pin: mcu_box1:PB5
step_pulse_duration:0.000000100

[box_stepper slot2]
runout_pin: mcu_box1:PA13
step_pin: mcu_box1:PC12
dir_pin: mcu_box1:PC11
enable_pin: !mcu_box1:PD2
microsteps: 16
rotation_distance: 13.6
white_pin: mcu_box1:PA14
red_pin: mcu_box1:PA15
step_pulse_duration:0.000000100

[box_stepper slot3]
runout_pin: mcu_box1:PA7
step_pin: mcu_box1:PC8
dir_pin: mcu_box1:PB2
enable_pin: !mcu_box1:PC10
microsteps: 16
rotation_distance: 13.6
white_pin: mcu_box1:PC4
red_pin: mcu_box1:PC5
step_pulse_duration:0.000000100

[heater_generic heater_box1]
heater_pin: mcu_box1:PA3
sensor_type: AHT20_F
i2c_bus: i2c3
#i2c_software_scl_pin = mcu_box1:PA8
#i2c_software_sda_pin = mcu_box1:PC9
i2c_mcu: mcu_box1
i2c_address: 56
control: pid
pid_Kp: 63.418
pid_Ki: 1.342
pid_Kd: 749.125
min_temp: -100
max_temp: 100
target_max_temp: 90

[verify_heater heater_box1]
max_error: 400
check_gain_time: 600
is_box_heater: True

[temperature_sensor heater_temp_a_box1]
sensor_type: NTC 100K MGB18-104F39050L32
sensor_pin: mcu_box1:PC1
min_temp: -100
max_temp: 130

[temperature_sensor heater_temp_b_box1]
sensor_type: NTC 100K MGB18-104F39050L32
sensor_pin: mcu_box1:PC2
min_temp: -100
max_temp: 130

[box_heater_fan heater_fan_a_box1]
pin: mcu_box1:PA4
heater: heater_box1
heater_temp: 35
stepper:
idle_timeout: 60

[box_heater_fan heater_fan_b_box1]
pin: mcu_box1:PA5
heater: heater_box1
heater_temp: 35
stepper:
idle_timeout: 60

[controller_fan board_fan_box1]
pin: mcu_box1:PA6
heater: heater_box1
stepper: box_stepper slot0, box_stepper slot1, box_stepper slot2, box_stepper slot3

[box_rfid card_reader_1]
cs_pin: mcu_box1:PC6

[box_rfid card_reader_2]
cs_pin: mcu_box1:PC7

[gcode_macro _BOX_SELECT_TOOL]
description: Select/load a QiDi Box tool, while skipping Orca's first post-PRINT_START startup T command once.
gcode:
    {% set tool = params.TOOL|int %}
    {% set slot = params.SLOT|string %}
    {% set slot_sync = printer.save_variables.variables.slot_sync|default('slot-1') %}
    {% set enable_box = printer.save_variables.variables.enable_box|default(0)|int %}

    {% set guard_active = 0 %}
    {% set guard_tool = -1 %}
    {% if printer["gcode_macro _STARTUP_TOOL_GUARD"] is defined %}
        {% set guard_active = printer["gcode_macro _STARTUP_TOOL_GUARD"].active|default(0)|int %}
        {% set guard_tool = printer["gcode_macro _STARTUP_TOOL_GUARD"].tool|default(-1)|int %}
    {% endif %}

    {% if guard_active == 1 and guard_tool == tool %}
        SET_GCODE_VARIABLE MACRO=_STARTUP_TOOL_GUARD VARIABLE=active VALUE=0
        SET_GCODE_VARIABLE MACRO=_STARTUP_TOOL_GUARD VARIABLE=tool VALUE=-1
        M118 T{tool} skipped: startup tool already handled by PRINT_START
    {% else %}
        {% if guard_active == 1 %}
            SET_GCODE_VARIABLE MACRO=_STARTUP_TOOL_GUARD VARIABLE=active VALUE=0
            SET_GCODE_VARIABLE MACRO=_STARTUP_TOOL_GUARD VARIABLE=tool VALUE=-1
        {% endif %}

        {% if enable_box == 1 %}
            {% if slot_sync != slot %}
                EXTRUDER_LOAD SLOT={slot}
            {% else %}
                M118 T{tool} skipped: {slot} already loaded
            {% endif %}
        {% endif %}
    {% endif %}

[gcode_macro T0]
gcode:
    {% set slot = printer.save_variables.variables.value_t0|default('slot0') %}
    _BOX_SELECT_TOOL TOOL=0 SLOT={slot}

[gcode_macro T1]
gcode:
    {% set slot = printer.save_variables.variables.value_t1|default('slot1') %}
    _BOX_SELECT_TOOL TOOL=1 SLOT={slot}

[gcode_macro T2]
gcode:
    {% set slot = printer.save_variables.variables.value_t2|default('slot2') %}
    _BOX_SELECT_TOOL TOOL=2 SLOT={slot}

[gcode_macro T3]
gcode:
    {% set slot = printer.save_variables.variables.value_t3|default('slot3') %}
    _BOX_SELECT_TOOL TOOL=3 SLOT={slot}

[gcode_macro UNLOAD_T0]
gcode:
    {% set slot = printer.save_variables.variables.value_t0|default('slot0') %}
    {% if printer.save_variables.variables.enable_box|default(0)|int == 1 %}
        EXTRUDER_UNLOAD SLOT={slot}
    {% endif %}

[gcode_macro UNLOAD_T1]
gcode:
    {% set slot = printer.save_variables.variables.value_t1|default('slot1') %}
    {% if printer.save_variables.variables.enable_box|default(0)|int == 1 %}
        EXTRUDER_UNLOAD SLOT={slot}
    {% endif %}

[gcode_macro UNLOAD_T2]
gcode:
    {% set slot = printer.save_variables.variables.value_t2|default('slot2') %}
    {% if printer.save_variables.variables.enable_box|default(0)|int == 1 %}
        EXTRUDER_UNLOAD SLOT={slot}
    {% endif %}

[gcode_macro UNLOAD_T3]
gcode:
    {% set slot = printer.save_variables.variables.value_t3|default('slot3') %}
    {% if printer.save_variables.variables.enable_box|default(0)|int == 1 %}
        EXTRUDER_UNLOAD SLOT={slot}
    {% endif %}

[gcode_macro T4]
gcode:
    {% set slot = printer.save_variables.variables.value_t4|default('slot4') %}
    _BOX_SELECT_TOOL TOOL=4 SLOT={slot}

[gcode_macro T5]
gcode:
    {% set slot = printer.save_variables.variables.value_t5|default('slot5') %}
    _BOX_SELECT_TOOL TOOL=5 SLOT={slot}

[gcode_macro T6]
gcode:
    {% set slot = printer.save_variables.variables.value_t6|default('slot6') %}
    _BOX_SELECT_TOOL TOOL=6 SLOT={slot}

[gcode_macro T7]
gcode:
    {% set slot = printer.save_variables.variables.value_t7|default('slot7') %}
    _BOX_SELECT_TOOL TOOL=7 SLOT={slot}

[gcode_macro UNLOAD_T4]
gcode:
    {% set slot = printer.save_variables.variables.value_t4|default('slot4') %}
    {% if printer.save_variables.variables.enable_box|default(0)|int == 1 %}
        EXTRUDER_UNLOAD SLOT={slot}
    {% endif %}

[gcode_macro UNLOAD_T5]
gcode:
    {% set slot = printer.save_variables.variables.value_t5|default('slot5') %}
    {% if printer.save_variables.variables.enable_box|default(0)|int == 1 %}
        EXTRUDER_UNLOAD SLOT={slot}
    {% endif %}

[gcode_macro UNLOAD_T6]
gcode:
    {% set slot = printer.save_variables.variables.value_t6|default('slot6') %}
    {% if printer.save_variables.variables.enable_box|default(0)|int == 1 %}
        EXTRUDER_UNLOAD SLOT={slot}
    {% endif %}

[gcode_macro UNLOAD_T7]
gcode:
    {% set slot = printer.save_variables.variables.value_t7|default('slot7') %}
    {% if printer.save_variables.variables.enable_box|default(0)|int == 1 %}
        EXTRUDER_UNLOAD SLOT={slot}
    {% endif %}

[gcode_macro T8]
gcode:
    {% set slot = printer.save_variables.variables.value_t8|default('slot8') %}
    _BOX_SELECT_TOOL TOOL=8 SLOT={slot}

[gcode_macro T9]
gcode:
    {% set slot = printer.save_variables.variables.value_t9|default('slot9') %}
    _BOX_SELECT_TOOL TOOL=9 SLOT={slot}

[gcode_macro T10]
gcode:
    {% set slot = printer.save_variables.variables.value_t10|default('slot10') %}
    _BOX_SELECT_TOOL TOOL=10 SLOT={slot}

[gcode_macro T11]
gcode:
    {% set slot = printer.save_variables.variables.value_t11|default('slot11') %}
    _BOX_SELECT_TOOL TOOL=11 SLOT={slot}

[gcode_macro UNLOAD_T8]
gcode:
    {% set slot = printer.save_variables.variables.value_t8|default('slot8') %}
    {% if printer.save_variables.variables.enable_box|default(0)|int == 1 %}
        EXTRUDER_UNLOAD SLOT={slot}
    {% endif %}

[gcode_macro UNLOAD_T9]
gcode:
    {% set slot = printer.save_variables.variables.value_t9|default('slot9') %}
    {% if printer.save_variables.variables.enable_box|default(0)|int == 1 %}
        EXTRUDER_UNLOAD SLOT={slot}
    {% endif %}

[gcode_macro UNLOAD_T10]
gcode:
    {% set slot = printer.save_variables.variables.value_t10|default('slot10') %}
    {% if printer.save_variables.variables.enable_box|default(0)|int == 1 %}
        EXTRUDER_UNLOAD SLOT={slot}
    {% endif %}

[gcode_macro UNLOAD_T11]
gcode:
    {% set slot = printer.save_variables.variables.value_t11|default('slot11') %}
    {% if printer.save_variables.variables.enable_box|default(0)|int == 1 %}
        EXTRUDER_UNLOAD SLOT={slot}
    {% endif %}

[gcode_macro T12]
gcode:
    {% set slot = printer.save_variables.variables.value_t12|default('slot12') %}
    _BOX_SELECT_TOOL TOOL=12 SLOT={slot}

[gcode_macro T13]
gcode:
    {% set slot = printer.save_variables.variables.value_t13|default('slot13') %}
    _BOX_SELECT_TOOL TOOL=13 SLOT={slot}

[gcode_macro T14]
gcode:
    {% set slot = printer.save_variables.variables.value_t14|default('slot14') %}
    _BOX_SELECT_TOOL TOOL=14 SLOT={slot}

[gcode_macro T15]
gcode:
    {% set slot = printer.save_variables.variables.value_t15|default('slot15') %}
    _BOX_SELECT_TOOL TOOL=15 SLOT={slot}
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

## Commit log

2026-04-06 Files added
    [fluidd.cfg, gcode_macro.cfg, printer.cfg]
2026-04-06 Update gcode_macro.cfg
    adjusted chamber circulation fan runtime. Should run for at least 2 hours.. first 30 minutes is enough to clear out VOCs but to filter out the smell completely needs more time.
    [gcode_macro.cfg]
2026-04-08 modifications added from https://github.com/qidi-community/Plus4-Wiki
    [gcode_macro.cfg, printer.cfg]
2026-04-09 please run a bed level if you restart klipper with my exact config files.. you could damage your machine!
    [fluidd.cfg, gcode_macro.cfg, saved_variables.cfg]
2026-04-09 adjusting z-offset calculations
    [gcode_macro.cfg]
2026-04-09 Minor revisions
    [gcode_macro.cfg]
2026-04-09 reverting this change..
    [gcode_macro.cfg]
2026-04-11 WARNING: nearly learned the hard way with this one.. you need two seperate printer profiles when NOT using the AMS and when you are using the AMS..
2026-04-11 Add important warning tips to README. Please read and understand them before printing.
2026-04-11 rewrite README for clarity and add important filament swap / QiDi Box warnings
2026-04-15 add manual bed/chamber temp reached console logging via SET_HEATER_TEMPERATURE override
    [gcode_macro.cfg]
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2026-04-17 fixing chamber heater not kicking on when print finishes... Needs to at least run for 2 hr.
    [gcode_macro.cfg]
2026-04-18 attempting to fix pause/cancel timeout.
    [gcode_macro.cfg]
2026-04-18 guard cancel motion during homing and print_start calibration to prevent unsafe bed/head moves
    [gcode_macro.cfg]
2026-04-18 reverting this for safety
    [gcode_macro.cfg]
2026-04-18 Update README.md
    clean up QiDi Box mods README section and improve filament saver install note
2026-04-19 fix start-up purge temp handling and improve homing/cancel parking behavior
    Slightly more detailed:
    fix purge temp logic, center after homing, and add safer cancel bed clearance
    [gcode_macro.cfg, printer.cfg]
2026-04-19 fix post-print chamber exhaust state handling in print end and cancel macros
    [gcode_macro.cfg]
2026-04-20 woops reverting this.. -0.15 safe calibration point.. as you can see I use -0.22
    [gcode_macro.cfg]
2026-04-20 Preserve and restore chamber heater target across homing and probing macros
    [gcode_macro.cfg]
2026-04-20 fix: use PURGETEMP for box poop flush during PRINT_START
    [gcode_macro.cfg]
2026-04-25 Add Orca Slicer support limitation notes
    * Add separate Orca_Slicer_README.md notes file
    * Document curved/arced underside support-interface issues
    * Link related Orca, Bambu Studio, and Cura support-distance issues
    * Add quick ASA support workaround values
    * Add preview/debug checklist for support-heavy prints
2026-04-25 adjusted.. using organic supports.. you can adjust z offset from print using a value of 0.05 here.
    May revert if parts are adhered to greatly.. doing testing
2026-04-25 getting a bit aggressive with the z offset from support layers.. This legit fixed my issues. :)
    I'm keeping 0.1mm z top offset here.. users will need to adjust if support adhesion is to close
2026-04-27 SAFE printer/process should be used when printing with delicate support structure that can be knocked easily.
    The printer/process labeled non-safe basically just disable Z hop or ignore crossing wall settings.. basically anything that doesn't use supports can be printed with the non-SAFE printer/process is the idea.
    Using SAFE will be generally recommended.. You're less likely to have a failed print from nozzle knocking support structure.
    process "SAFE" just avoids crossing walls.. this isn't as important unless if you're printing with highly delicate organic support structure.
2026-04-29 Added universal spool weight mod I now recommend.
    Added link to poop box which has an open poop chute I like.. Helps by allowing the purged filament to fall straight down into box instead of flying off table.
2026-04-29 added two test print files for different calibrations.
    [4_color_flush_test.3mf, support_top_z_dist-curve&straight_test.3mf]
2026-04-29 changed my mind.. use this color flush test instead for calibrating flush values
    [4_color_flush_test.3mf]
2026-05-01 adjusted filament change gcode... Optimize your flushing volumes for less waste. I suggest running a calibration test for optimal flushing volume range.. seems instead of default 0.3 value 0.7 is saf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
2026-05-01 added note about TPU.. I'm slowing down my current orca slicer process to 70%.
2026-05-04 Add fail-closed probe/error safety handling
    - Replace virtual_sdcard on_error_gcode CANCEL_PRINT path with a no-motion fail-closed macro
    - Reduce probe retry hammering after inconsistent samples
    - Clamp unsafe Z/sub-zoffset behavior after suspicious probe results
    - Reduce allowed negative Z travel to limit bed/nozzle crash risk
    - Avoid SDCARD_RESET_FILE during sdcard-driven error cleanup
    - Keep cancel/startup guard behavior focused on preventing motion from invalid probe/homing states
    [gcode_macro.cfg, printer.cfg]
2026-05-06 Tune board fan behavior and support separation
    - Adjust board fan control so it no longer runs continuously when the MCU board is already cool
    - Raise the board fan minimum temperature threshold from 10C to 35C, since 10C is unrealistic outside freezing environments
    - Keep board cooling focused on normal operating conditions while still allowing the fan to ramp when needed
    - Adjust support Z offset from 0.10mm to 0.12mm for easier support separation
    [printer.cfg]
2026-05-06 Update printer.cfg
    adjusted.. should not be 0 for min fan speed.. to much fluctuation.
    I am leaving to turn off below 35c. Still testing
    [printer.cfg]
2026-05-06 Update printer.cfg
    changed my mind.. don't touch this
    [printer.cfg]
2026-05-06 Update printer.cfg
    this target temp works better for me.
    [printer.cfg]
2026-05-07 chamber fan cooling to often with 65c target.. I suggest monitoring your temps depending on how many holes you've plugged on your machine will give you a variable target temp.. 69.0 seems to be the s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
    My minimum while printing with 55c chamber is 65c.. 70.0 is a good baseline but I'm just going to show my actual value when I can here.
    [printer.cfg]
2026-05-07 Improve QiDi Box / AMS startup safety and loaded-tool handling
    - Add explicit AMS mode handling to PRINT_START via AMS=1 / AMS=0
    - Track the currently loaded AMS tool with ams_loaded_tool instead of unloading at print end
    - Leave filament loaded after successful AMS prints and save the final tool index
    - On the next AMS print, compare requested tool against the tracked loaded tool
    - If a different AMS tool is requested, cut/unload the currently loaded filament before loading the new slot
    - Fail closed when AMS mode is requested but QiDi Box is disabled or unavailable
    - Refuse AMS startup when filament is detected but no AMS-loaded tool is tracked, preventing accidental external-roll use
    - Up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
    [gcode_macro.cfg, printer.cfg, saved_variables.cfg]
2026-05-07 Fix NO AMS purge temp
    - Pass PURGETEMP to NO AMS PRINT_START
    - Use max filament temp for nozzle clearing
    - Keep AMS=0 external-spool behavior
2026-05-07 Update README AMS tracking notes
    - Add loaded-tool tracking reference for QiDi Box / AMS
    - Document roll-to-tool value mapping
    - Note manual screen load/unload state caveat
    - Clarify NO AMS profile usage for external spool prints
2026-05-07 Track AMS loaded tool after tool changes
    - Save ams_loaded_tool after successful AMS color swaps
    - Keep loaded-tool state accurate if a print is canceled after changing colors
    - Reduce stale tracking risk when leaving AMS filament loaded between prints
2026-05-07 Improve cancel safety near trash/lever zone
    - Allow startup cancels to escape the trash/lever zone when XY is homed
    - Move forward to Y250 before disabling steppers if cancel occurs at Y > 300
    - Continue skipping cancel motion during active homing
    - Preserve normal cancel park behavior outside startup
    [gcode_macro.cfg]
2026-05-07 Tighten cancel trash-zone threshold
    - Trigger trash escape only at Y >= 307
    - Avoid false positives near printable rear edge
    [gcode_macro.cfg]
2026-05-08 Revert AMS loaded-tool tracking
    - Restore end-of-print AMS unload behavior
    - Remove ams_loaded_tool tracking from tool changes and print end
    - Simplify PRINT_START to load the requested AMS slot fresh
    - Keep AMS=1 / AMS=0 profile separation
    - Keep NO AMS profile dumb and free of QiDi Box tool calls
    [gcode_macro.cfg, saved_variables.cfg]
2026-05-08 I had an extruder jam with 70% speed with TPU.. I now suggest all prints to just go down to 50% speed in web interface.
2026-05-10 Adjust PRINT_START startup flow
    - keep purge-temp filament prep
    - disable chamber during probing
    - re-enable chamber after calibration
    - remove chamber wait before printing
    [gcode_macro.cfg]
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2026-05-13 test lower ABS/ASA cooling profiles
    Keep the original cooling profile as a baseline while testing reduced fan settings.
    Avoid disabling cooling completely for now. Some geometry, especially thin or small-detail parts, may still benefit from limited airflow to help layers solidify cleanly.
    Continue testing low-cooling behavior before making it the default.
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2026-05-20 removed profiles that disable z-hop.. I almost see zero benifit from doing this tbh.. you're just more likely to have a failed print due to clashing with a thin support structure and even if your pri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
2026-05-22 Test manual-feed sensor handling for TPU + other minor fixes
    [gcode_macro.cfg]
2026-05-23 Experimenting
    Fix QiDi Box toolchange purge minimum while leaving strong Orca flush values unchanged
    Adds a dynamic minimum purge floor for weak Orca auto-calculated flush values. If Orca already calculates a strong purge, such as 104 mm filament or higher, no extra purge is added.
2026-05-23 Experimenting
    Add zero-flush bypass for QiDi Box purge calibration
    Allows manual purge testing by skipping extra toolchange purge when Orca flush_length is 0. Keeps the dynamic minimum purge floor for weak auto-calculated values, while leaving strong manual/auto flush values unchanged.
    Also adds the AMS purge calibration .3mf and Orca process used for testing.
    [AMS+Purge+Calibration_Plus4.3mf, support_top_z_dist-curve&straight_test.3mf]
2026-05-23 minor revisiont to infil angle.
    [AMS+Purge+Calibration_Plus4.3mf]
2026-05-23 Tune QiDi Box purge floor for 1.0 flush multiplier
    [AMS+Purge+Calibration_Plus4.3mf]
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2026-05-27 Remove automatic AMS unload from end G-code
    Updated the QIDI Box/AMS end G-code to leave filament loaded after prints instead of running UNLOAD_FILAMENT automatically. This avoids unnecessary end-of-print feeder activity, reduces failure risk after a completed part, and leaves unload control to the next job or manual filament handling.
    Strangley leaving this behavior in place can lead to MCU Timeout rarely at the end of a print... Minutely less stress on your cutter long term as well.
    When you send a new print with a different starting color the printer should swap to the color it needs cleanly.
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2026-05-27 disabled arc fitting.. mistake klipper doesn't need this setting
2026-05-28 Add QiDi Box slot-load guard macros
    Adds box1.cfg with T0-T15 macros that check the currently synced slot before calling EXTRUDER_LOAD. This prevents duplicate tool commands from reloading an already-loaded QiDi Box slot while keeping normal slot changes and unload macros untouched.
    [box1.cfg]
2026-05-28 adjusted toolhead park when print is cancelled.
    [gcode_macro.cfg]
2026-05-28 Fix unsafe AMS toolchange Z lift
    [gcode_macro.cfg]
2026-05-28 Add adaptive QiDi Box startup flush control
    [gcode_macro.cfg]
2026-05-28 Fix AMS startup slot sync and fake toolchange guard
2026-05-28 Revert AMS startup and filament-change edits
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2026-06-05 reworked AMS startup order to avoid extra heater load during homing and probing
    Moved QiDi Box startup after G28, Z_TILT_ADJUST, and G29 so AMS/tool handling no longer overlaps with the sensitive probing path. Cleaned up slicer start code so PRINT_START owns heating, chamber restore, tool selection, and AMS startup.
    [gcode_macro.cfg, printer.cfg, saved_variables.cfg]
2026-06-06 added optional host-load tuning notes and screen service toggle
    Updated the README to point users toward the optional Plus4 tuning script. Added support for disabling/re-enabling the QIDI screen/xindi stack through the tuning menu instead of documenting manual sy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
    [gcode_macro.cfg, printer.cfg]
2026-06-06 reduced QiDi bed level probing load
    Updated QiDi bed leveling macros to use the reduced-load calibration path. Keeps the QIDI z-offset workflow while removing the duplicated G31/G29 chain and using a 7x7 mesh to reduce probe load durin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
    [gcode_macro.cfg]
2026-06-06 optimized QiDi bed leveling macros
    Updated QiDi bed leveling to keep the original 9x9 mesh density while removing the duplicated G31/G29 chain. Uses the QIDI z-offset workflow with a lighter calibration path for 60C, 80C, 100C, and 11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
    [gcode_macro.cfg]
2026-06-07 cleaned nozzle before startup probing
    Updated PRINT_START to clear the nozzle before Z_TILT_ADJUST / G32 / G29 so ooze or leftover filament cannot affect probe and z-offset accuracy.
    [gcode_macro.cfg]
2026-06-07 clean up macro comments
    Reviewed gcode_macro.cfg comments to keep useful notes while making them shorter, cleaner, and easier to follow. No macro behavior changed.
    [gcode_macro.cfg]
2026-06-07 woops reverted default z offset value
    [gcode_macro.cfg]
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2026-06-09 Add external KlipperScreen client guide and update Plus4 docs.
    * Add laptop-based KlipperScreen setup guide to keep the UI off the Plus4 host.
    * Update root README with external KlipperScreen notes and performance tuning context.
    * Add webcam config notes for mjpg-streamer frame dropping and reduced stream load.
    * Shorten CR Box section in the root README and keep the detailed build notes in docs.
2026-06-10 Move startup purge into filament profiles
    * Keep printer start G-code limited to PRINT_START and basic startup setup.
    * Move adaptive purge out of Machine start G-code so Orca runs it after tool selection.
    * Fix AMS preview color mismatch where startup purge could show as T0 instead of the selected AMS slot.
    * Add shared ABS/ASA filament start purge for AMS and NO AMS workflows.
    * Add slower TPU filament start purge for manual spool / NO AMS printing.
    * Keep AMS behavior controlled only by printer profile using AMS=1 or AMS=0.
2026-06-10 Fix active filament material in G-code filenames
    * Update Orca filename format to use `{filament_type[initial_tool]}`.
    * Fix AMS exports being named after slot 1 material instead of the active print tool.
    * Keep material name accurate for T0/T1/T2/T3 and NO AMS workflows.
    * Confirm T3 / AMS slot 4 ASA exports now generate ASA filenames instead of ABS.
2026-06-10 Reorder AMS startup so the requested filament loads and flushes before nozzle cleaning and Z calibration. Keeps NO AMS startup path unchanged.
    [gcode_macro.cfg]
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2026-06-11 Clean up Plus4 AMS startup flow by loading the actual initial tool before startup purge, nozzle wipe, and Z calibration. Updated AMS profiles to use `initial_tool`, fixed filament purge-line conditio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
    [gcode_macro.cfg, printer.cfg]
2026-06-11 Fix Plus4 AMS startup double-load behavior
    Reordered AMS startup so the requested initial tool loads before nozzle prep and Z calibration, then added a one-time startup tool guard to skip Orca’s post-PRINT_START `T#` command. This prevents duplicate cut/load behavior after calibration while preserving normal later AMS toolchanges.
    [box1.cfg, gcode_macro.cfg]
2026-06-11 minor fix
    [gcode_macro.cfg]
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2026-06-15 Paper Joint Tape is highly recommended but you must hold the joint tape down on all sides and it must be TIGHT with zero give.. if the Paper Joint Tape is floating at any point the POM Filament will 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
    Thinking about getting some "3M 468MP adhesive transfer tape" to hold the Paper Joint Tape down...
    alternatively clean your plate super well.. add a good bit of 3DLAC and either hope and pray 110c will work or if it nearly works push up to 120c bed plate.
    Chamber temp must stay at 55c.. It may be good to preheat.
2026-06-23 Lower macro acceleration to 8800 to reduce toolhead cable stress during fast travel moves
    [gcode_macro.cfg]
2026-06-23 Document aluminum tension bar upgrade and stock bar warping
2026-06-29 Prevent redundant XY homing during Box unload
    Home Z before entering the purge area, preserve QIDI’s safe X/Y/X homing order when XY is unknown, and skip unnecessary XY rehoming when those axes are already established.
    [gcode_macro.cfg]
2026-07-04 Refine startup nozzle wipe and Z-tilt positioning
    [gcode_macro.cfg]
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
